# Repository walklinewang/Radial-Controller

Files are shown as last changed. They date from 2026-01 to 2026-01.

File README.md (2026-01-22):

# Radial Controller

    

## 项目概述

Radial Controller 是一款基于 CH5xx 系列芯片开发的 USB 径向控制器（旋转编码器），通过 Microsoft Radial Controller 协议与 Windows 系统通信，可作为系统级径向控制器使用。

该设备采用模块化设计，包含硬件驱动、USB 通信和灯效控制等功能，支持通过 Web 界面进行参数配置，具有良好的扩展性和易用性。

### 主要功能特性

- **Microsoft Radial Controller 协议**：通过微软径向控制器协议与 Windows 系统通信，提供系统级径向控制功能
- **EC11 编码器支持**：支持旋转检测和按钮功能，可配置旋转灵敏度
- **WS2812 灯效控制**：内置 WS2812 灯带驱动，支持多种灯效模式和亮度调节
- **按键渐亮/渐暗特效**：按下编码器按钮时，LED 渐暗；释放时，LED 渐亮，提升用户体验
- **Web 配置工具**：通过浏览器进行设备参数配置，无需安装额外软件
- **EEPROM 配置存储**：非易失性存储用户配置，断电后不会丢失
- **CDC 串口通信**：支持通过串口进行命令控制和调试

### 使用方法

Radial Controller 通过 Microsoft Radial Controller 协议与 Windows 系统通信，仅支持 Windows 10/11，可在系统设置中配置径向控制器功能。

#### 基本操作

- **旋转**：顺时针/逆时针旋转编码器，发送相应的角度值
- **按钮**：按下编码器按钮，发送按钮按下/释放事件
- **灯效**：旋转编码器、按下/释放按钮时，LED 灯效会发生变化，可通过配置工具调整灯效参数

### 串口命令

Radial Controller 支持通过 CDC 串口进行命令控制和调试。这些命令主要用于在没有硬件外设的情况下进行开发验证和测试：

| 命令 | 功能说明 | 参数 |
|:---:|---|:---:|
| `show_menu` | 模拟径向控制器按钮长按 | 无 |
| `click` | 模拟径向控制器按钮点击 | 无 |
| `rotate_left` | 模拟向左旋转（逆时针） | 无，默认旋转 -10 度 |
| `rotate_right` | 模拟向右旋转（顺时针） | 无，默认旋转 10 度 |

这些命令可以通过串口终端（如 PuTTY、Arduino IDE 串口监视器）发送，用于测试设备功能和验证固件的正常工作。

## 软件依赖

### 核心库

该项目使用了第三方库 **ch55xduino**，这是一个为 CH55X 系列 USB MCU 提供的 Arduino 兼容编程 API。

- **项目地址**：[https://github.com/DeqingSun/ch55xduino](https://github.com/DeqingSun/ch55xduino)

## 编译上传固件

### 1. 使用 Arduino IDE

1. **安装 ch55xduino 库**：

    - 打开 Arduino IDE
    - 进入`文件 > 首选项`，在 "附加开发板管理器网址" 中添加：
        ```
        https://raw.githubusercontent.com/DeqingSun/ch55xduino/ch55xduino/package_ch55xduino_mcs51_index.json
        ```
    - 进入`工具 > 开发板 > 开发板管理器`
    - 搜索 "ch55xduino" 并安装

2. **配置开发环境**：

    - 选择开发板：`工具 > 开发板 > CH55x Boards > CH552 Board`
    - 设置 USB RAM：`工具 > USB Settings > USER CODE w/266 USB Ram`
    - 选择上传方法：`工具 > 上传方式 > USB`

3. **进入 Bootloader 模式**：

    - 按住开发板上的 BOOT 按钮不放
    - 将开发板通过 USB 连接到电脑
    - 释放 BOOT 按钮，此时开发板进入 Bootloader 模式

    > 注意：除首次上传外，都需要手动进入 Bootloader 模式

4. **编译与上传**：

    - 点击 Arduino IDE 中的 "验证" 按钮编译代码
    - 点击 "上传" 按钮将代码烧录到芯片

### 2. 使用 WCH 官方工具

1. **下载 WCH 官方工具**：

    - 访问 WCH 官方网站：[http://www.wch.cn/downloads/WCHISPTool_Setup_exe.html](http://www.wch.cn/downloads/WCHISPTool_Setup_exe.html)
    - 下载并安装 WCHISPTool (Studio) 工具

2. **准备固件文件**：

    - 下载项目提供的[预编译固件文件](https://github.com/walklinewang/Radial-Controller/releases)

3. **进入 Bootloader 模式**：

    - 按住开发板上的 BOOT 按钮不放
    - 将开发板通过 USB 连接到电脑
    - 释放 BOOT 按钮，此时开发板进入 Bootloader 模式

    > 注意：除首次上传外，都需要手动进入 Bootloader 模式

4. **使用 WCHISPTool (Studio) 烧录固件**：

    - 打开 WCHISPTool (Studio) 工具
    - 在 "设备类型" 中选择 "CH552"
    - 点击 "搜索设备" 按钮，工具将自动识别 Bootloader 模式下的 CH552 芯片
    - 在 "目标程序文件" 中选择编译好的 `.hex` 固件文件
    - 勾选 "下载完成后运行目标程序" 选项
    - 点击 "下载" 按钮开始烧录固件
    - 烧录完成后，设备将自动运行新烧录的固件

## Web Config 工具

Radial Controller 提供了基于 Web 的配置工具，可通过浏览器进行设备参数配置。

### 配置步骤

1. 连接设备：将 Radial Controller 连接到计算机
2. 打开配置工具：在浏览器中访问 [https://webconfig.walkline.wang](https://webconfig.walkline.wang)
3. 连接设备：点击 "连接设备" 按钮，选择 Radial Controller 设备
4. 加载配置：设备连接成功后，将自动加载当前配置
5. 调整参数：
    - **灯珠数量**：调整 WS2812 灯珠数量
    - **亮度等级**：调整灯带亮度
    - **颜色顺序**：选择灯珠颜色顺序
    - **灯效模式**：选择灯效模式
    - **流动灯效触发间隔**：调整流动灯效变化速度
    - **渐变灯效持续时长**：调整按键按下/释放时的渐变灯效速度
    - **顺时针旋转角度**：设置顺时针旋转时发送的角度值
    - **逆时针旋转角度**：设置逆时针旋转时发送的角度值
    - **每转动一齿触发动作次数**：调整编码器旋转灵敏度
6. 保存配置：点击 "保存设置" 按钮，保存配置到设备

### 配置参数说明

| 参数 | 说明 | 范围 | 默认值 |
|:---:|---|:---:|:-----:|
| `led_count` | WS2812 灯珠数量 | 1~10 | 4 |
| `brightness` | 亮度等级 | 0~4 | 3 |
| `color_order` | 颜色顺序 | GRB/RGB | GRB |
| `effect_mode` | 灯效模式 | 0 | 0 |
| `rotate_interval` | 流动灯效触发间隔 | 20~500 | 40 |
| `fade_duration` | 渐变灯效持续时长 | 100~300 | 150 |
| `step_per_teeth` | 旋转灵敏度（每齿触发次数） | 1~2 | 2 |
| `rotate_cw` | 顺时针旋转角度（度） | 1~360 | 10 |
| `rotate_ccw` | 逆时针旋转角度（度） | -360~-1 | -10 | 

## 使用 USB VendorID 过滤设备

### 设备识别原理

USB 设备通过 VendorID（供应商 ID）和 ProductID（产品 ID）进行唯一识别。Radial Controller 使用了开源硬件通用的 VendorID `0x1209`。

### 固件中的 VendorID

在 `src/CdcRadial/USBconstant.c#L18` 中定义了设备的 VendorID：

```c
.VendorID = 0x1209,
```

这个定义会被包含在 USB 设备描述符中，当设备连接到计算机时，操作系统会读取这些信息来识别设备类型和制造商。

### Web 配置工具中的 VendorID

在 `tools/web_config/script.js#L29` 中，Web 配置工具使用了相同的 VendorID 来过滤目标设备：

```javascript
this.USB_VENDOR_ID = 0x1209;
```

当用户点击"连接设备"按钮时，Web 配置工具会使用这个 VendorID 过滤出所有匹配的 Radial Controller 设备。

## 参考项目

### Microsoft Radial Controller Design Guidelines

[Microsoft 径向控制器设计指南](https://learn.microsoft.com/en-us/windows-hardware/design/component-guidelines/radial-controller-designs) 提供了关于径向控制器的设计规范和最佳实践，包括：

- 硬件设计原则
- HID 报告描述符规范
- 与 Windows 系统集成的最佳实践

该指南为 Radial Controller 项目提供了标准化的 HID 报告格式和交互设计参考，确保设备能够与 Windows 系统无缝集成。

### CH552 旋钮控制器项目

[[星火计划] 丐 dial](https://oshwhub.com/morempty/CH552gyin-liang-xuan-niu) 是一个基于 CH552 芯片的旋钮控制器开源项目，提供了硬件电路设计参考，加速了项目的开发进程。

## 故障排除

### 1. 设备无法被识别

**问题**：设备连接到计算机后，无法被识别或显示为未知设备

**解决方案**：

1. 检查 USB 连接线是否完好
2. 尝试不同的 USB 端口
3. 重新烧录固件
4. 检查设备驱动是否正确安装（Windows 系统）

### 2. Web Config 工具无法连接设备

**问题**：Web Config 工具无法找到或连接设备

**解决方案**：

1. 确保使用支持 Web Serial API 的浏览器（Chrome、Edge、Opera）
2. 检查设备是否已正确连接
3. 清除浏览器缓存并重新加载页面
4. 检查浏览器是否有 Web Serial API 访问权限

### 3. 旋转编码器无响应

**问题**：旋转编码器时，计算机或灯效无响应

**解决方案**：

1. 检查编码器与芯片的连接是否正确
2. 检查编码器是否损坏
3. 调整旋转灵敏度配置
4. 重新烧录固件

### 4. 灯效异常

**问题**：LED 灯珠不亮或显示异常颜色

**解决方案**：

1. 检查灯珠数量配置是否正确
2. 检查颜色顺序配置是否正确
3. 检查灯珠与芯片的连接是否正确
4. 检查灯珠是否损坏

## 许可证

Radial Controller 项目采用 MIT 许可证开源，详见 [LICENSE](LICENSE) 文件。

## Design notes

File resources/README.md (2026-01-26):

# 资源目录说明

该目录包含了项目中使用的 3D 模型和其他资源文件。

## 1. 其它文档

* [docs/灯效颜色过渡分析.md](./docs/灯效颜色过渡分析.md)：LED 灯效颜色过渡分析文档，包含了颜色过渡的数学计算和实现细节

## 2. 3D 模型文件

* [models/Controller_v4.3mf](https://raw.githubusercontent.com/walklinewang/Radial-Controller/refs/heads/main/resources/models/Controller_v4.3mf)：Bambu Studio 项目文件，已进行简单配置，可直接打印使用
* [models/Controller_v4.f3z](https://raw.githubusercontent.com/walklinewang/Radial-Controller/refs/heads/main/resources/models/Controller_v4.f3z)：Autodesk Fusion 存档文件，上传后可进行二次编辑
* [models/Controller_v4_底壳.stl](https://raw.githubusercontent.com/walklinewang/Radial-Controller/refs/heads/main/resources/models/Controller_v4_底壳.stl)：底壳模型文件
* [models/Controller_v4_上盖.stl](https://raw.githubusercontent.com/walklinewang/Radial-Controller/refs/heads/main/resources/models/Controller_v4_上盖.stl)：上盖模型文件
* [models/Controller_v4_锁止环.stl](https://raw.githubusercontent.com/walklinewang/Radial-Controller/refs/heads/main/resources/models/Controller_v4_锁止环.stl)：锁止环模型文件

> [!NOTE]
> 模型上盖适配的旋转编码器规格：
> 
> - 底座尺寸：11.7mm x 12mm
> - 底座高度：4.5mm
> - 手柄高度：10mm
> - 手柄直径：6mm

> [!TIP]
> 要适配其它高度尺寸，可以在 Fusion 中进行修改（实体 → 修改 → 更改参数）。

## 3. PCB 相关文件

* [pcb/3D_Controller.step](https://raw.githubusercontent.com/walklinewang/Radial-Controller/refs/heads/main/resources/pcb/3D_Controller.step)：PCB 模型文件
* [pcb/Gerber_Controller_v0.1.zip](https://raw.githubusercontent.com/walklinewang/Radial-Controller/refs/heads/main/resources/pcb/Gerber_Controller_v0.1.zip)：PCB 制板文件

## 4. 图片文件

* PCB 2D 预览

    | 正面 | 反面 |
    | :-----: | :----: |
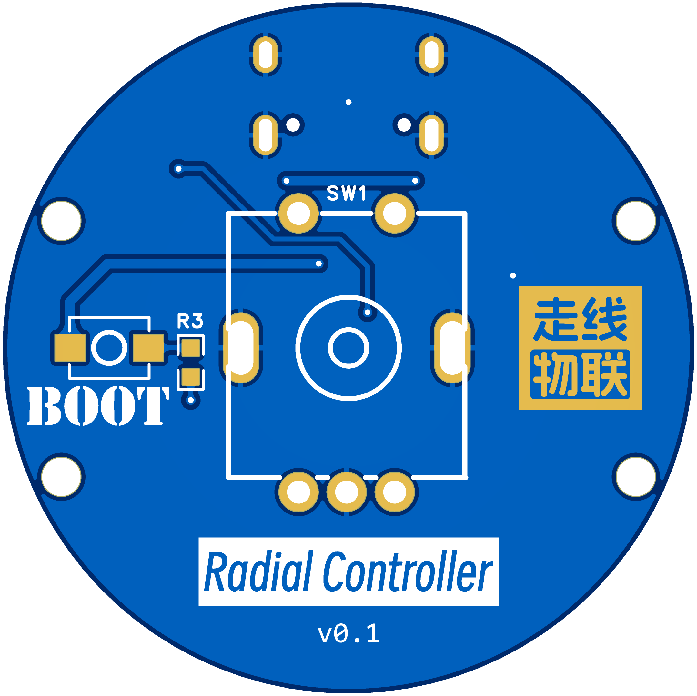
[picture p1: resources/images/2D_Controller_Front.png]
PCB 2D 正面
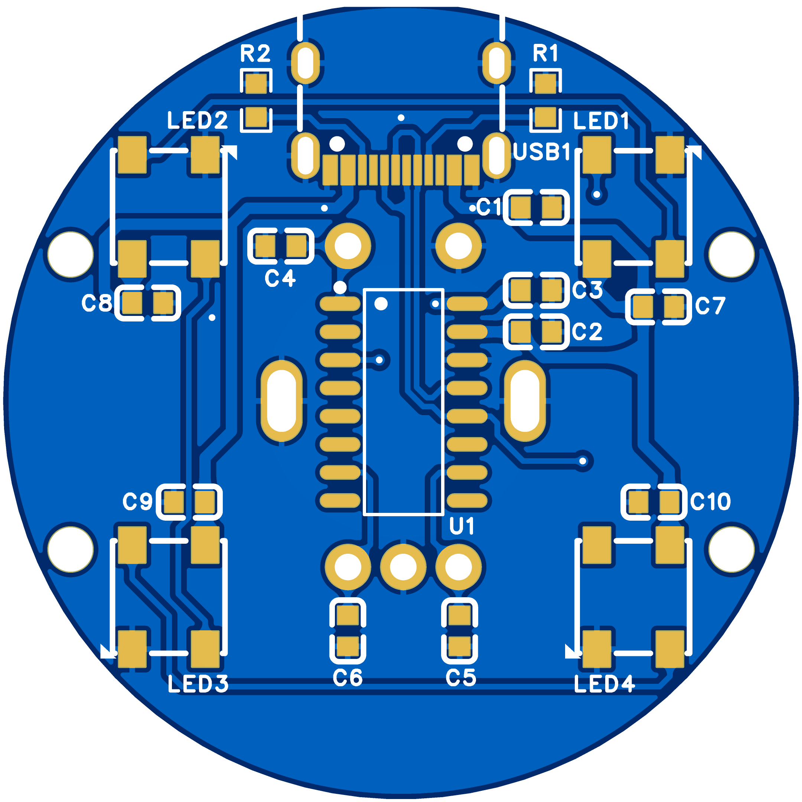
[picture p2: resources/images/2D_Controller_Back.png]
PCB 2D 反面
    |  |  |

* PCB 3D 预览

    | 正面 | 反面 |
    | :-----: | :----: |
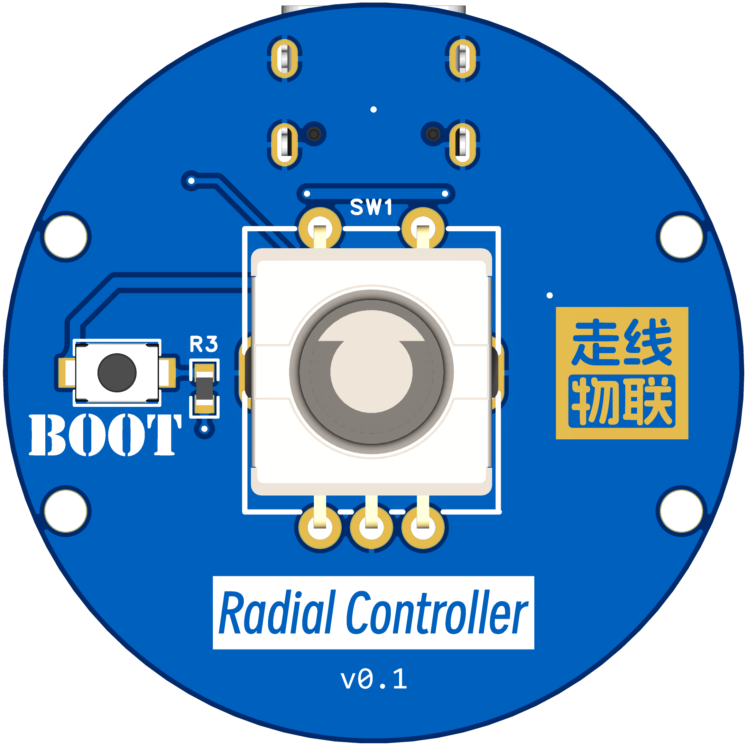
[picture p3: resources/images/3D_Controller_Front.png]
PCB 3D 正面
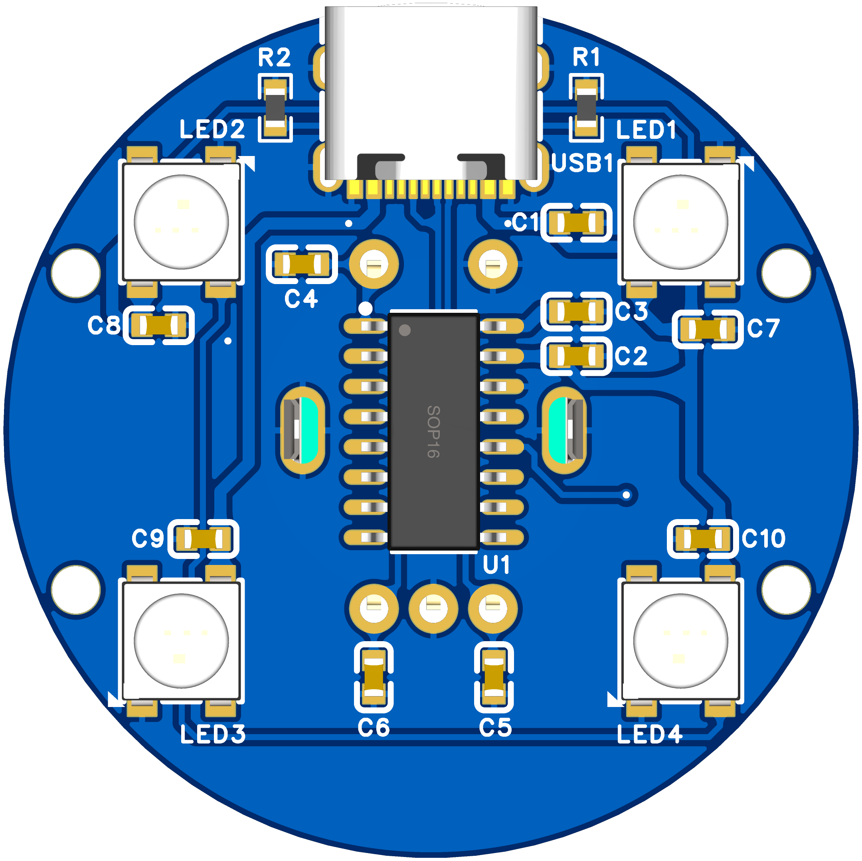
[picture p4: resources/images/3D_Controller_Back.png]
PCB 3D 反面
    |  |  |

* 外壳渲染

    | 外壳 |
    | :-----: |
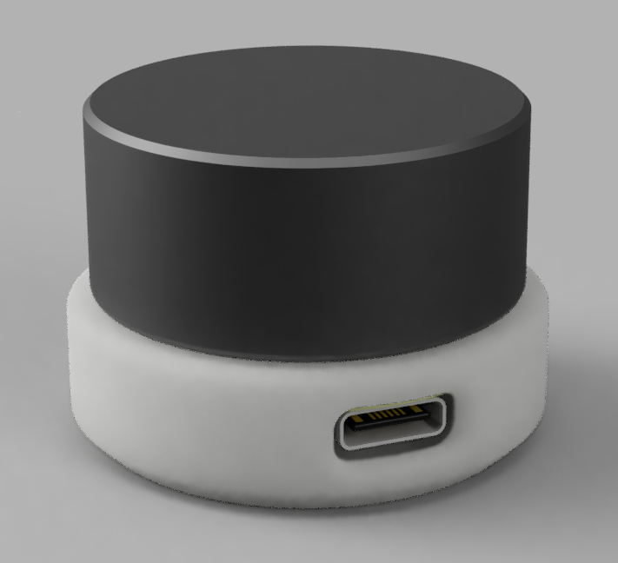
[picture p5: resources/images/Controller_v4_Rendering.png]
外壳渲染
    |  |

* Web Config 工具网页截图

    | Web Config 工具 |
    | :-----: |
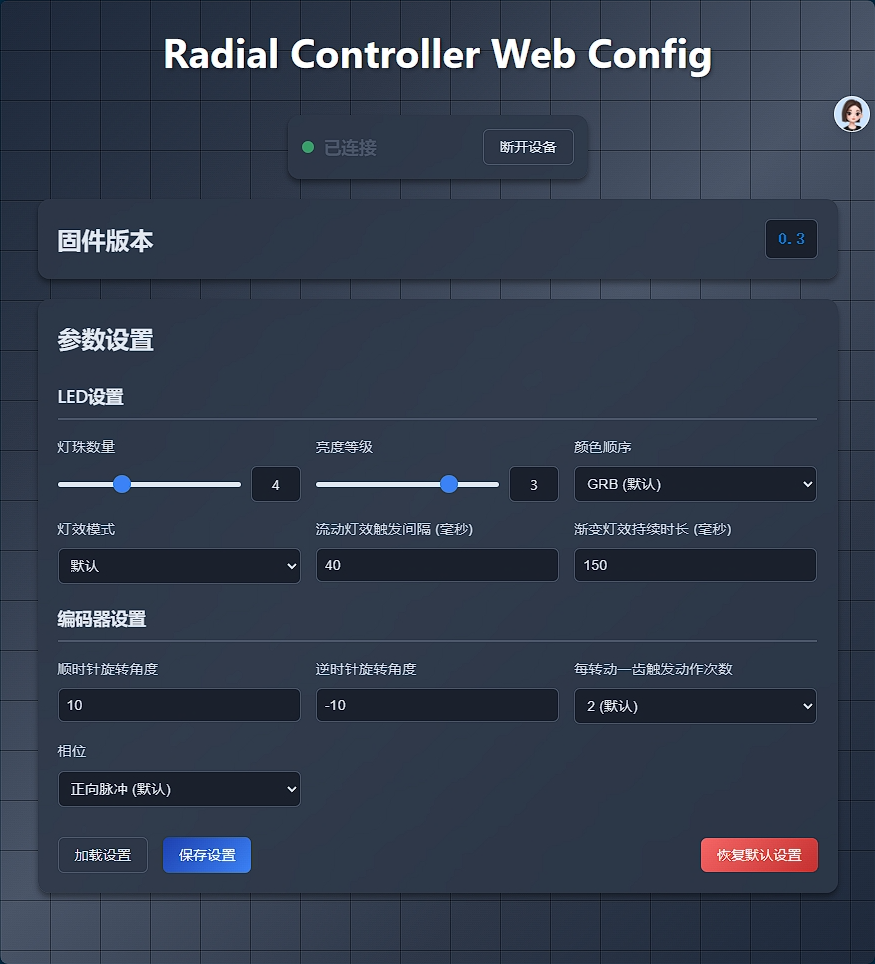
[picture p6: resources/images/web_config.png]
Web Config 工具
    |  |

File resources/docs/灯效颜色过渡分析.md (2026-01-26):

# 灯效颜色过渡分析

## 一、函数概述

`WS2812_FillRotationEffectColor` 函数负责为 LED 灯珠填充流动灯效的颜色，实现平滑的颜色渐变过渡效果。

## 二、颜色渐变原理

### 2.1 分段设计

函数将颜色渐变分为三个主要阶段，共 30 个分段（offset 从 0 到 29）：

| 阶段 | Offset 范围 | 颜色渐变方向 | 渐变步数 |
|:----:|:---:|:---:|:---:|
| 1 | 0~9 | 红 → 绿 | 10 步 |
| 2 | 10~19 | 绿 → 蓝 | 10 步 |
| 3 | 20~29 | 蓝 → 红 | 10 步 |

### 2.2 渐变步长

每个颜色渐变阶段使用步长为 25 的增量进行颜色计算：

- 步长计算：255 / 10 ≈ 25
- 这意味着每个颜色通道的值会以 25 为单位递增或递减

## 三、完整周期颜色变化序列

### 3.1 阶段 1：红 → 绿渐变（Offset 0~9）

```
红色 → 橙色 → 黄色 → 绿色
```

**详细变化过程**

- Offset 0~3：红色逐渐减弱，绿色逐渐增强 → 从纯红色过渡到橙色
- Offset 3~6：红色继续减弱，绿色继续增强 → 从橙色过渡到黄色
- Offset 6~9：红色接近消失，绿色占据主导 → 从黄色过渡到纯绿色

### 3.2 阶段 2：绿 → 蓝渐变（Offset 10~19）

```
绿色 → 青色 → 蓝色
```

**详细变化过程**

- Offset 10~13：绿色逐渐减弱，蓝色逐渐增强 → 从纯绿色过渡到青色
- Offset 13~16：绿色继续减弱，蓝色继续增强 → 从青色过渡到天蓝色
- Offset 16~19：绿色接近消失，蓝色占据主导 → 从天蓝色过渡到纯蓝色

### 3.3 阶段 3：蓝 → 红渐变（Offset 20~29）

```
蓝色 → 靛蓝色 → 紫色 → 红色
```

**详细变化过程**

- Offset 20~23：蓝色逐渐减弱，红色逐渐增强 → 从纯蓝色过渡到靛蓝色
- Offset 23~26：蓝色继续减弱，红色继续增强 → 从靛蓝色过渡到紫色
- Offset 26~29：蓝色接近消失，红色占据主导 → 从紫色过渡到纯红色

## 四、完整颜色循环

### 4.1 颜色环顺序

一个完整的颜色周期（30 步）包含以下颜色序列：

```
红色 → 橙色 → 黄色 → 绿色 → 青色 → 蓝色 → 靛蓝色 → 紫色 → 红色
```

### 4.2 视觉效果

- **快速过渡**：每个颜色过渡有 10 个中间步骤，过渡速度较快
- **无跳跃**：颜色变化连续，没有突然的颜色跳跃
- **全色域覆盖**：覆盖了从红色到紫色的所有主要颜色

## 五、多 LED 协同效果

### 5.1 四 LED 颜色分布示例

假设有 4 个 LED 灯珠（LED 0-3），在某个时刻的颜色分布：

| LED 索引 | 色相偏移 | 当前颜色 |
|:---:|:---:|:---:|
| 0 | 0° | 红色 |
| 1 | 60° | 黄色 |
| 2 | 120° | 绿色 |
| 3 | 180° | 青色 |

### 5.2 动态流动效果

当 `count` 递增时，所有 LED 的色相值同时增加，形成以下效果：

- LED 0：红色 → 橙色 → 黄色 → ...
- LED 1：黄色 → 绿色 → 青色 → ...
- LED 2：绿色 → 青色 → 蓝色 → ...
- LED 3：青色 → 蓝色 → 靛蓝色 → ...

视觉上，整个颜色环会沿着 LED 排列方向流动，形成彩虹般的流动效果。

## 六、平滑过渡特性验证

### 6.1 平滑度评估

✅ **足够的渐变步数**：每个颜色过渡阶段有 10 个步骤
✅ **适中的步长**：步长为 25，既保证了过渡速度又不会占用过多计算资源
✅ **连续的颜色变化**：没有颜色跳跃或突变
✅ **完整的色域覆盖**：覆盖了所有主要颜色

### 6.2 性能优化

- 使用整数运算，避免浮点数计算，提高执行效率
- 预计算亮度级别，减少运行时计算量
- 每个 LED 的颜色计算独立，便于并行处理

## 七、流动速度调整

可以通过修改 `ws2812.rotate_interval` 值调整颜色流动速度：

- 减小值：流动速度加快
- 增大值：流动速度减慢

## 八、总结

`WS2812_FillRotationEffectColor` 函数通过精心设计的分段渐变算法，成功实现了以下目标：

1. ✅ **快速的颜色过渡**：在 30 个分段内实现了从红色到紫色的完整色相环渐变
2. ✅ **自然的颜色变化**：颜色序列符合人眼对颜色的感知习惯
3. ✅ **高效的计算方式**：使用整数运算和预计算，确保在单片机上的高效运行
4. ✅ **良好的视觉效果**：多 LED 协同工作时，形成彩虹般的流动光效

该函数为 LED 流动灯效提供了坚实的技术基础，能够满足大多数视觉效果需求。

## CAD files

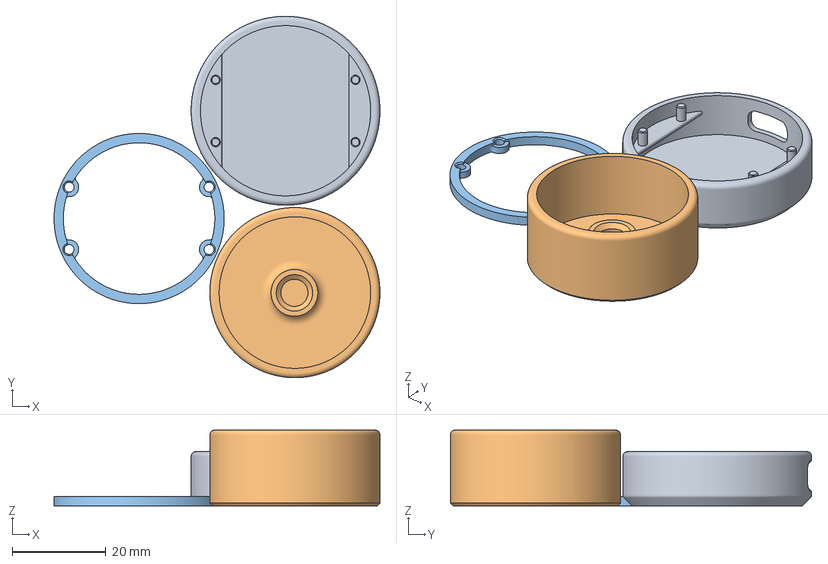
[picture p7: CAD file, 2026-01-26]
resources/models/Controller_v4.3mf
69.7 x 77.2 x 16.2 mm
底壳
上盖
锁止环

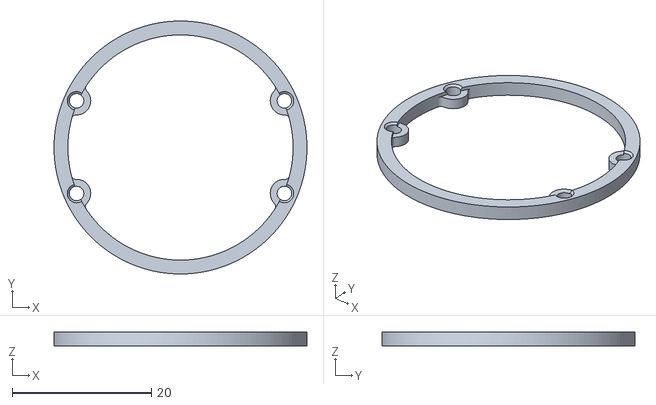
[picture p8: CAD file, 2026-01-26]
resources/models/Controller_v4_锁止环.stl
36.4 x 36.4 x 2.00

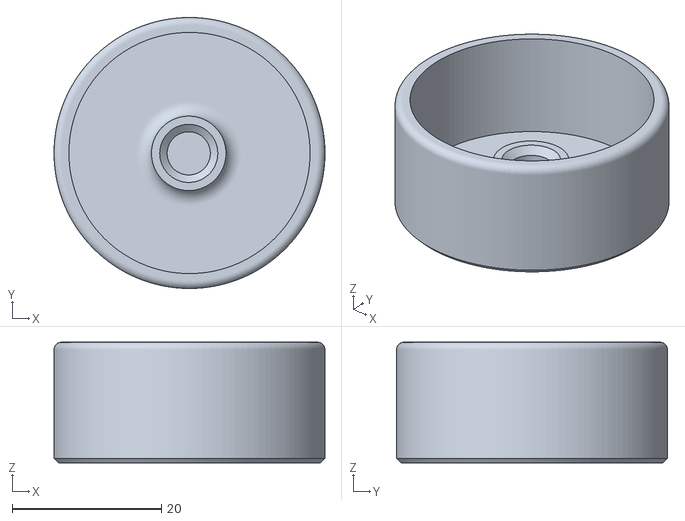
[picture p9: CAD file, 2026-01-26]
resources/models/Controller_v4_上盖.stl
36.4 x 36.4 x 16.2

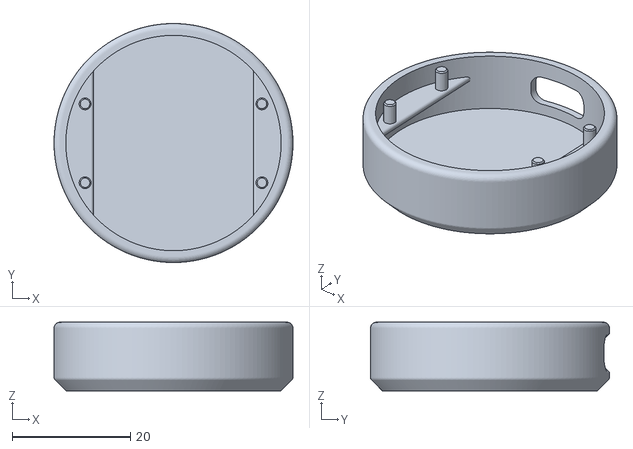
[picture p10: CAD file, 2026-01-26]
resources/models/Controller_v4_底壳.stl
40.4 x 40.4 x 11.6

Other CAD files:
resources/models/Controller_v4.f3z

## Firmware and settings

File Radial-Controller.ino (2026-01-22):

/*
  Radial Controller

  Copyright © 2026 Walkline Wang (walkline@gmail.com)
  Github: https://github.com/walklinewang/Radial-Controller
*/
#ifndef USER_USB_RAM
#error "This firmware needs to be compiled with a USER USB setting"
#error "Tools--> USB Settings--> USER CODE w/266 USB Ram"
#endif

#include "src/CdcRadial/USBCDC.h"
#include "src/CdcRadial/USBRadial.h"
#include "src/Common.h"
#include "src/Drivers/EC11.h"
#include "src/Drivers/EEPROM.h"
#include "src/Drivers/MyWS2812.h"

#define CMD_CONFIG_MODE_ENABLED "config_mode_enabled"
#define CMD_CONFIG_MODE_TIMEOUT "config_mode_timeout"
#define CMD_CONFIG_LOAD_SETTINGS "load_settings"
#define CMD_CONFIG_SAVE_SETTINGS "save_settings"
#define CMD_CONFIG_RESET_SETTINGS "reset_settings"
#define CMD_CONFIG_HEARTBEAT "heartbeat"
#define CMD_CONFIG_SAVE_SETTINGS_PREFIX CMD_CONFIG_SAVE_SETTINGS "="
#define CMD_SUCCESS_SUFFIX "_success"
#define CMD_FAILED_SUFFIX "_failed"

#define CMD_TEST_SHOW_MENU "show_menu"
#define CMD_TEST_CLICK "click"
#define CMD_TEST_ROTATE_LEFT "rotate_left"
#define CMD_TEST_ROTATE_RIGHT "rotate_right"

#define HEARTBEAT_TIMEOUT 4000 // 心跳超时时间

void update_config();
void process_ec11_operation();
void process_heartbeat();
void process_serial_data();
void process_commands(uint8_t *command);

// 接收缓冲区，用于存储从串口接收的命令
uint8_t receive_buf[50];
uint8_t receive_ptr = 0;
bool data_received = false;

// 上一次编码器旋转方向
ec11_direction_t last_direction = EC11_DIR_CW;

// 是否为配置模式
bool is_config_mode = false;

// 心跳检测相关变量
uint32_t heartbeat_last_received = 0; // 最后一次收到心跳的时间戳

void setup() {
    USBInit();

    // 从 EEPROM 读取配置参数
    EEPROM_LoadConfig();

    // 初始化 EC11 编码器
    EC11_Init(EC11_PIN_A, EC11_PIN_B, EC11_PIN_K);

    // 执行配置初始化
    update_config();
}

void loop() {
    process_serial_data();

    if (data_received) {
        process_commands(receive_buf);

        receive_ptr = 0;
        data_received = false;
    }

    if (is_config_mode) {
        process_heartbeat();
        return;
    }

    process_ec11_operation();

    // 根据当前灯效状态执行对应灯效
    if (WS2812_GetBrightness() == 0) {
        WS2812_Clear();
    } else {
        if (WS2812_GetEffectState() == WS2812_EFFECT_STATE_ROTATION) {
            WS2812_ShowRotationEffect(last_direction);
        } else {
            WS2812_ShowFadeEffect();
        }
    }
}

/**
 * @brief 配置更新后执行的初始化操作
 */
void update_config() {
    // 设置 EC11 编码器转动一齿触发次数
    EC11_SetStepPerTeeth(EEPROM_GetStepPerTeeth());

    // 设置 EC11 编码器相位
    EC11_SetPhase(EEPROM_GetPhase());

    // 重新初始化 WS2812 LED
    WS2812_Init(WS2812_PIN, EEPROM_GetLedCount(), EEPROM_GetColorOrder());

    // 设置 WS2812 LED 亮度
    WS2812_SetBrightness(EEPROM_GetBrightness());

    // 设置 LED 流动灯效触发间隔
    WS2812_SetRotateEffectInterval(EEPROM_GetRotateEffectInterval());

    // 设置 LED 渐变灯效持续时长
    WS2812_SetFadeEffectDuration(EEPROM_GetFadeEffectDuration());
}

/**
 * @brief 处理 EC11 编码器操作
 */
void process_ec11_operation() {
    // 更新 EC11 编码器状态
    EC11_UpdateStatus();

    // 处理编码器旋转
    ec11_direction_t direction = EC11_GetDirection();

    // 更新方向状态
    if (direction != EC11_DIR_NONE && direction != last_direction) {
        last_direction = direction;
    }

    if (direction == EC11_DIR_CW) {
        // 顺时针旋转，发送正值，单位：度
        Radial_SendData(0, EEPROM_GetRotateCW());
    } else if (direction == EC11_DIR_CCW) {
        // 逆时针旋转，发送负值，单位：度
        Radial_SendData(0, EEPROM_GetRotateCCW());
    }

    // 处理编码器按键
    if (EC11_IsKeyChanged()) {
        ec11_key_state_t key_state = EC11_GetKeyState();

        if (key_state == EC11_KEY_PRESSED) {
            Radial_SendData(1, 0);     // 按键按下
            WS2812_SetFadeOutEffect(); // 渐暗效果
        } else {
            Radial_SendData(0, 0);    // 按键释放
            WS2812_SetFadeInEffect(); // 渐亮效果
        }
    }
}

/**
 * @brief 处理心跳包命令
 */
void process_heartbeat() {
    if (millis() - heartbeat_last_received >= HEARTBEAT_TIMEOUT) {
        // 心跳超时，退出配置模式
        is_config_mode = false;
        heartbeat_last_received = 0; // 重置心跳时间戳

        USBSerial_println(CMD_CONFIG_MODE_TIMEOUT);
        USBSerial_flush();
    }
}

/**
 * @brief 处理串口数据
 */
void process_serial_data() {
    bool is_save_command = false;

    while (USBSerial_available()) {
        uint8_t serial_char = USBSerial_read();

        // 针对 save_settings 命令的特殊处理
        if (receive_ptr >= strlen(CMD_CONFIG_SAVE_SETTINGS_PREFIX)) {
            is_save_command =
                (memcmp(receive_buf, CMD_CONFIG_SAVE_SETTINGS_PREFIX,
                        strlen(CMD_CONFIG_SAVE_SETTINGS_PREFIX)) == 0);
        }

        if (is_save_command) {
            receive_buf[receive_ptr] = serial_char;
            receive_ptr++;

            // save_settings=命令格式：14字节前缀 + 30字节数据 + 1字节换行符
            if (receive_ptr >=
                strlen(CMD_CONFIG_SAVE_SETTINGS_PREFIX) + 30 + 1) {
                receive_buf[receive_ptr] = '\0';
                data_received = true;
                break;
            }
        }
        // 对于其他命令，使用换行符或回车符作为结束标记
        else if ((serial_char == '\n') || (serial_char == '\r')) {
            receive_buf[receive_ptr] = '\0';

            if (receive_ptr > 0) {
                data_received = true;
                break;
            }
        } else {
            receive_buf[receive_ptr] = serial_char;
            receive_ptr++;

            if (receive_ptr >= sizeof(receive_buf) - 1) {
                receive_buf[receive_ptr] = '\0';
                data_received = true;
                break;
            }
        }
    }
}

/**
 * @brief 处理 CDC 接收到的命令
 * @param command 命令字符串
 */
void process_commands(uint8_t *command) {
    if (strcmp((const uint8_t *)command, CMD_CONFIG_MODE_ENABLED) == 0) {
        is_config_mode = true;

        // 初始化心跳检测，设置最后收到心跳时间为当前时间
        heartbeat_last_received = millis();

        USBSerial_print(CMD_CONFIG_MODE_ENABLED);
        USBSerial_println(CMD_SUCCESS_SUFFIX);
        USBSerial_flush();
    } else if (strcmp((const uint8_t *)command, CMD_CONFIG_HEARTBEAT) == 0) {
        if (is_config_mode) {
            heartbeat_last_received = millis(); // 更新最后收到心跳的时间戳
        }
    } else if (strcmp((const uint8_t *)command, CMD_CONFIG_LOAD_SETTINGS) ==
               0) {
        // 从 EEPROM 加载配置参数
        EEPROM_LoadConfig();

        eeprom_config_t *config = EEPROM_GetConfigData();
        uint8_t *config_bytes = (uint8_t *)config;

        // 发送配置数据前缀
        USBSerial_print("config=");
        // 发送 32 字节配置数据
        USBSerial_print_n(config_bytes, CONFIG_STRUCT_SIZE);

        USBSerial_println();
        USBSerial_flush();
    } else if (memcmp((const uint8_t *)command, CMD_CONFIG_SAVE_SETTINGS_PREFIX,
                      strlen(CMD_CONFIG_SAVE_SETTINGS_PREFIX)) == 0) {
        eeprom_config_t *config = EEPROM_GetConfigData();

        // 跳过"save_settings="前缀（14字节）
        const uint8_t *data_ptr =
            (const uint8_t *)(command +
                              strlen(CMD_CONFIG_SAVE_SETTINGS_PREFIX));
        uint8_t *config_bytes = (uint8_t *)config;

        // 复制 30 字节配置数据，跳过前 2 字节（version 和 revision）
        memcpy(config_bytes + 2, data_ptr, 30);

        // 保存配置到EEPROM
        if (EEPROM_SaveConfig() == EEPROM_STATUS_OK) {
            USBSerial_print(CMD_CONFIG_SAVE_SETTINGS);
            USBSerial_println(CMD_SUCCESS_SUFFIX);
            USBSerial_flush();
        } else {
            // 保存失败，从 EEPROM 加载配置参数
            EEPROM_LoadConfig();

            USBSerial_print(CMD_CONFIG_SAVE_SETTINGS);
            USBSerial_println(CMD_FAILED_SUFFIX);
            USBSerial_flush();
        }

        // 执行配置更新后的初始化操作
        update_config();
    } else if (strcmp((const uint8_t *)command, CMD_CONFIG_RESET_SETTINGS) ==
               0) {
        EEPROM_Reset();
        EEPROM_SaveConfig();

        // 执行配置更新后的初始化操作
        update_config();

        USBSerial_print(CMD_CONFIG_RESET_SETTINGS);
        USBSerial_println(CMD_SUCCESS_SUFFIX);
        USBSerial_flush();

        /* 以下为测试用命令 */
    } else if (strcmp((const uint8_t *)command, CMD_TEST_SHOW_MENU) == 0) {
        // 模拟径向控制器按钮按下
        Radial_SendData(1, 0); // button=1(按下), degree=0(无旋转)

        // 保持按下状态 500 毫秒
        delay(500);

        // 执行按钮释放动作
        Radial_SendData(0, 0); // button=0(释放), degree=0(无旋转)
    } else if (strcmp((const uint8_t *)command, CMD_TEST_CLICK) == 0) {
        // 立即模拟径向控制器按钮按下
        Radial_SendData(1, 0); // button=1(按下), degree=0(无旋转)

        // 保持按下状态 100 毫秒
        delay(50);

        // 执行按钮释放动作
        Radial_SendData(0, 0); // button=0(释放), degree=0(无旋转)
    } else if (strcmp((const uint8_t *)command, CMD_TEST_ROTATE_LEFT) == 0) {
        // 模拟向左旋转（逆时针），单次旋转值为 -10 度
        Radial_SendData(0, -10); // button=0(释放), degree=-10(向左旋转)
    } else if (strcmp((const uint8_t *)command, CMD_TEST_ROTATE_RIGHT) == 0) {
        // 模拟向右旋转（顺时针），单次旋转值为 10 度
        Radial_SendData(0, 10); // button=0(释放), degree=10(向右旋转)
    }
}

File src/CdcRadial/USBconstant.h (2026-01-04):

#ifndef __CONST_DATA_H__
#define __CONST_DATA_H__

// clang-format off
#include <stdint.h>
#include "include/ch5xx.h"
#include "include/ch5xx_usb.h"
#include "usbCommonDescriptors/StdDescriptors.h"
#include "usbCommonDescriptors/CDCClassCommon.h"
#include "usbCommonDescriptors/HIDClassCommon.h"
// clang-format on

#define EP0_ADDR 0
#define EP1_ADDR 10
#define EP2_ADDR 20
#define EP3_ADDR 148

#define SET_LINE_CODING                                                        \
    0X20 // Configures DTE rate, stop-bits, parity, and number-of-character
#define GET_LINE_CODING                                                        \
    0X21 // This request allows the host to find out the currently configured
         // line coding.
#define SET_CONTROL_LINE_STATE                                                 \
    0X22 // This request generates RS-232/V.24 style control signals.

#define CDC_NOTIFICATION_EPADDR 0x81
#define CDC_NOTIFICATION_EPSIZE 0x08
#define CDC_TX_EPADDR 0x82
#define CDC_RX_EPADDR 0x02
#define CDC_TXRX_EPSIZE 0x40

#define KEYBOARD_EPADDR 0x83
#define KEYBOARD_EPSIZE 8

/* Type Defines: */
/** Type define for the device configuration descriptor structure. This must be
 * defined in the application code, as the configuration descriptor contains
 * several sub-descriptors which vary between devices, and which describe the
 * device's usage to the host.
 */
typedef struct {
    USB_Descriptor_Configuration_Header_t Config;
    USB_Descriptor_Interface_Association_t CDC_IAD;

    // CDC Command Interface
    USB_Descriptor_Interface_t CDC_CCI_Interface;
    USB_CDC_Descriptor_FunctionalHeader_t CDC_Functional_Header;
    USB_CDC_Descriptor_FunctionalACM_t CDC_Functional_ACM;
    USB_CDC_Descriptor_FunctionalUnion_t CDC_Functional_Union;
    USB_Descriptor_Endpoint_t CDC_NotificationEndpoint;

    // CDC Data Interface
    USB_Descriptor_Interface_t CDC_DCI_Interface;
    USB_Descriptor_Endpoint_t CDC_DataOutEndpoint;
    USB_Descriptor_Endpoint_t CDC_DataInEndpoint;

    // Keyboard HID Interface
    USB_Descriptor_Interface_t HID_Interface;
    USB_HID_Descriptor_HID_t HID_KeyboardHID;
    USB_Descriptor_Endpoint_t HID_ReportINEndpoint;

} USB_Descriptor_Configuration_t;

/** Enum for the device interface descriptor IDs within the device. Each
 * interface descriptor should have a unique ID index associated with it, which
 * can be used to refer to the interface from other descriptors.
 */
enum InterfaceDescriptors_t {
    INTERFACE_ID_CDC_CCI = 0, /**< CDC CCI interface descriptor ID */
    INTERFACE_ID_CDC_DCI = 1, /**< CDC DCI interface descriptor ID */
    INTERFACE_ID_HID = 2,     /**< HID interface descriptor ID */
};

extern __code USB_Descriptor_Device_t DeviceDescriptor;
extern __code USB_Descriptor_Configuration_t ConfigurationDescriptor;
extern __code uint8_t LanguageDescriptor[];
extern __code uint16_t SerialDescriptor[];
extern __code uint16_t ProductDescriptor[];
extern __code uint16_t CDCDescriptor[];
extern __code uint16_t ManufacturerDescriptor[];
extern __code uint8_t ReportDescriptor[];

#endif

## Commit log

2026-01-04 chore: 添加项目基础配置文件
    - 添加.gitignore忽略build目录
    - 添加.clang-format代码格式化配置
    - 添加MIT许可证文件
2026-01-04 feat(USB): 添加径向控制器USB通信功能
    实现径向控制器的USB通信功能，包括CDC串口和HID设备支持。新增USB描述符、端点配置和数据处理逻辑，支持按钮和旋钮数据的传输。
    添加USB初始化、中断处理和端点回调函数，确保设备能够正确枚举并与主机通信。
    主要功能：
    - 支持CDC串口通信
    - 实现HID径向控制器报告传输
    - 添加USB端点配置和中断处理
    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
2026-01-04 feat: 添加EC11编码器、WS2812 LED和EEPROM驱动实现
    - 添加EC11编码器驱动，支持旋转方向和按键状态检测
    - 添加WS2812 LED驱动，支持颜色设置、流动灯效和亮度控制
    - 添加EEPROM驱动，用于存储和读取设备配置参数
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2026-01-04 feat(web_config): 新增径向控制器网页配置工具（WIP）
    添加网页版径向控制器配置工具，包含以下功能：
    - 串口连接管理
    - LED参数配置界面
    - 配置保存与重置功能
    - 浏览器兼容性检测
    - 响应式UI设计
2026-01-04 feat: 添加径向控制器主程序实现编码器和LED控制功能
    实现径向控制器主程序功能，包括：
    - 初始化EC11编码器和WS2812 LED
    - 处理编码器旋转和按键事件
    - 支持串口命令配置参数
    - 实现LED灯效控制
    - 支持EEPROM存储配置
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2026-01-05 refactor(web_config): 重构界面布局和串口助手逻辑（WIP）
    - 重新组织配置界面布局，调整参数配置和版本信息区域位置
    - 优化按钮布局，将功能按钮分组并添加分隔线
    - 在SerialAssistant类中添加命令和响应常量
    - 改进配置模式启用流程，添加响应验证
    - 清理未使用的CSS样式，简化样式表
    - 调整连接按钮文本为"连接设备/断开设备"
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2026-01-05 style(web_config): 更新界面文本和样式
    - 将"参数配置"统一修改为"参数设置"
    - 调整配置区域的底部边距
    - 更新未连接设备提示文本
    - 修改固件版本默认显示符号
2026-01-05 feat(串口通信): 优化配置数据传输并增加二进制解析功能（WIP）
    - 重构配置数据获取逻辑，使用二进制结构体传输替代单个参数传输
    - 修改web配置工具以支持二进制配置数据的解析和处理
    - 调整串口缓冲区大小限制并优化通信流程
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2026-01-06 refactor(EEPROM): 优化配置数据的读写逻辑
    - 将循环变量从uint16_t改为uint8_t以节省内存
    - 显式处理版本号和修订号的写入
    - 在结构体注释中添加字段偏移量便于维护
    - 调整EEPROM写入逻辑以匹配新的结构体布局
2026-01-06 feat(串口处理): 增加配置保存和加载功能并优化命令处理
    - 增加 save_settings 和 load_settings 命令处理
    - 移除调试打印语句优化性能
    - 扩展接收缓冲区大小以支持配置数据
    - 优化配置模式相关变量命名
    - 增加 reset_settings 命令支持
    [Radial-Controller.ino]
2026-01-06 feat(串口助手): 添加心跳机制并优化配置模式处理
    - 添加心跳包功能，定期发送心跳请求保持连接
    - 移除CONFIG_MODE_DISABLE命令及相关响应
    - 新增CONFIG_MODE_TIMEOUT响应处理配置模式超时
    - 优化serial_wait_for_data方法支持响应过滤
    - 重构方法命名遵循统一风格
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2026-01-07 refactor(串口通信): 使用宏定义优化命令字符串处理
    将硬编码的命令字符串替换为宏定义，提高代码可维护性
    统一命令响应格式，使用_SUCCESS和_FAILED后缀
    修复字符串比较中的类型转换问题
    [Radial-Controller.ino]
2026-01-07 refactor(web_config): 重构串口助手类并改进资源管理
    - 统一变量命名风格，使用下划线命名法
    - 合并初始化方法，优化事件监听器设置
    - 增强资源释放逻辑，确保正确关闭串口连接
    - 更新响应常量名称以更准确描述状态
    - 改进错误处理和状态显示方法
2026-01-09 feat(EC11): 添加编码器每齿触发次数配置功能
    - 添加 step_per_teeth 配置项
    - 允许设置 EC11 编码器每转动一齿触发动作的次数（1或2次）
    - 在 EEPROM 中存储该配置并在配置更新时自动应用
    - 更新 web 配置工具以支持该参数的设置
2026-01-09 fix(WS2812/EEPROM): 调整默认亮度等级为3并反转亮度级别数组
    将WS2812驱动和EEPROM配置中的默认亮度等级从1改为3
    同时反转BRIGHT_LEVELS数组顺序，使亮度级别与数值对应更直观
    [EEPROM.c]
2026-01-09 feat(web_config): 重构配置界面并增强参数验证功能
    - 重构HTML结构，简化版本信息显示并移除不必要的分隔线
    - 调整CSS样式，优化响应式布局和参数分组显示
    - 实现参数分组功能，将LED和编码器设置分开显示
    - 为数值参数添加滑块控件支持
    - 增强参数验证逻辑，包括实时输入过滤和范围检查
    - 添加参数保存前的全局验证功能
    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
2026-01-09 style(web_config): 更新界面为深色科技风格主题
    重构整个web配置工具的UI样式，将浅色主题改为深色科技风格
    - 修改背景为科技感网格纹理和渐变效果
    - 调整所有组件颜色以适配深色主题
    - 增强视觉层次和交互反馈
    - 统一控件样式并添加平滑过渡效果
2026-01-11 feat(web_config): 添加网站图标并优化样式和代码格式
    - 添加favicon.svg作为网站图标
    - 优化CSS背景样式的格式以提高可读性
    - 清理JavaScript代码中的多余空格和格式
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2026-01-12 fix(EEPROM): 修正配置版本号和修订号的值
    将配置版本号从1改为0，修订号从0改为1，以匹配当前硬件配置需求
2026-01-12 fix(EC11): 将阈值变量类型从uint8_t改为int8_t
    修改阈值变量类型以支持负值，满足编码器旋转事件触发的需求
2026-01-12 docs: 更新 README 文档，添加 WCH 官方工具烧录指南
    - 添加使用 WCHISPTool 烧录固件的详细步骤
    - 完善 Arduino IDE 烧录流程，明确进入 Bootloader 模式的方法
    - 重新组织故障排除章节，添加编号提高可读性
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2026-01-13 refactor: 重构LED效果处理和配置更新逻辑
    - 将UpdateConfigAfterChange重命名为update_config并扩展功能
    - 简化LED效果状态检查逻辑，移除不必要的tick计数器
    - 优化效果处理函数命名，增加旋转效果间隔和渐变持续时间配置
    - 使用uint8_t替代unsigned char提高代码一致性
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2026-01-14 docs: 更新 README 以反映新增的按键渐亮/渐暗特效
    - 添加按键渐亮/渐暗特效功能描述
    - 更新灯效相关参数说明，包括新增的渐变持续时间配置
    - 调整故障排除部分的编号格式
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2026-01-15 style(web_config): 优化样式和状态显示逻辑
    - 更新滑块数值显示样式，改进视觉一致性和可读性
    - 修改串口配置属性命名以符合标准
    - 简化端口状态检查逻辑
    - 改进状态消息显示方式，支持对象直接输出
2026-01-15 fix(EC11): 将计数器变量类型从uint8_t改为int8_t
    修复编码器计数器可能溢出的问题，当反向旋转时count会变为负数，原uint8_t类型无法正确表示负值
2026-01-15 fix(WS2812): 在旋转效果中添加缺失的WS2812_Show调用
    添加WS2812_Show()调用以确保旋转效果更新后立即显示颜色变化
2026-01-16 feat(EC11): 添加相位配置支持以兼容不同硬件连接
    添加 ec11_phase_t 枚举和相位转换逻辑，使驱动能够适配 A 相或 B 相超前的硬件连接
2026-01-16 feat(EEPROM): 添加EC11编码器相位配置支持并改进LED颜色顺序类型
    - 新增EC11编码器相位配置字段及相关函数
    - 将LED颜色顺序类型改为枚举类型ws2812_color_order_t
    - 更新默认配置和参数验证逻辑
2026-01-16 fix: 修复配置保存失败时未回滚配置的问题
    当配置保存失败时，从EEPROM重新加载配置以确保系统使用正确的参数
2026-01-16 feat(web_config): 增加相位参数并优化UI布局
    - 在配置参数中添加相位选择功能
    - 调整连接状态区域宽度和居中显示
    - 优化滑块数值显示的内边距
    - 为下拉框添加实时更新功能
    - 改进保存设置后的反馈提示
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2026-01-18 refactor(WS2812): 重构LED驱动代码并优化颜色处理
    - 使用枚举类型定义颜色顺序，提高代码可读性
    - 增加LED数据缓冲区大小定义，支持动态配置
    - 优化颜色设置逻辑，使用函数封装不同颜色顺序处理
    - 改进渐变效果实现，增加颜色数据保存功能
    - 简化引脚选择逻辑，使用预处理指令替代运行时判断
2026-01-18 refactor(EEPROM): 优化配置参数处理并移除冗余依赖
    - 使用常量定义替代硬编码值，提高可维护性
    - 优化EEPROM读写操作，减少重复计算
    - 移除未使用的Arduino.h头文件
    - 将EEPROM_GetConfigData()声明为extern inline
    - 使用memset初始化保留空间
2026-01-18 refactor(EC11): 优化编码器配置处理并添加内联声明
    - 使用常量替代硬编码的步进阈值配置
    - 将 EC11_GetDirection 函数声明为 extern inline
    - 移除冗余注释并保持代码风格一致
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2026-01-18 docs: 更新命令和配置参数文档
    - 将旋转命令从 rotate_l/rotate_r 改为 rotate_left/rotate_right 以提高可读性
    - 调整配置参数名称和描述，使其更准确
    - 更新默认值和参数范围
2026-01-18 fix(web_config): 修复滑块值显示在特定容器中的问题
    修改滑块值显示逻辑，确保在包含'slider-container'类的父元素中正确查找并更新显示值
2026-01-19 fix(SerialAssistant): 确保资源释放操作在finally块中执行
    - 修改多个方法将资源释放操作从catch块移到finally块，确保资源
    在任何情况下都能被正确释放
    - 同时为重置设置操作添加成功提示弹窗
2026-01-19 refactor(串口处理): 将串口数据处理逻辑提取为独立函数
    - 重构串口数据处理逻辑，将其从主循环中提取为独立的 process_serial_data 函数
    - 重命名 received 变量为 data_received 以提高可读性
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2026-01-20 feat(WS2812): 新增获取LED颜色功能并优化灯效
    - 添加WS2812_GetPixel函数用于获取单个LED颜色
    - 调整亮度级别数值以改善视觉效果
    - 重构旋转灯效算法，使用60段平滑渐变
    - 在清空LED时添加短暂延时确保硬件稳定
    - 优化渐变灯效的性能和颜色计算
2026-01-20 refactor(串口处理): 提取串口数据处理逻辑到独立函数并优化变量命名
    - 将串口数据处理逻辑从主循环提取到独立的 process_serial_data 函数
    - 重命名 received 为 data_received 以提高可读性
    - 调整 LED 显示逻辑以处理亮度为零的情况
2026-01-20 docs: 更新README以反映Windows专属支持和参数格式调整
    - 修改协议说明为仅支持Windows系统
    - 更新参数范围表示方式为波浪线(~)
    - 调整默认亮度值和灯珠数量
    - 添加Windows平台徽章
    - 优化文档结构和措辞
2026-01-20 fix: 更新固件修订号为3
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2026-01-26 feat(resources): 添加控制器相关资源文件和文档
    添加控制器 v4 的 3D 模型文件、PCB 设计文件、渲染图片和灯效颜色过渡分析文档
    [Controller_v4.3mf, Controller_v4.f3z, Controller_v4_上盖.stl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]

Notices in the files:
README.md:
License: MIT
